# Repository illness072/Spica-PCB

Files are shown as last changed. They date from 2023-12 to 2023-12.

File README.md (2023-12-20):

# Spica PCB

PCB Data for Spica Keyboard

Spica is a 38-keys keyboard inspired by the Gemini Keyboard layout by zk-phi(@zk-phi). It was named by Sumiso(@kutsuhimo3).

* Gemini Keyboard by @zk-phi
  * https://github.com/zk-phi/gemini-keyboard

* Case Data
  * https://github.com/illness072/Spica-case/

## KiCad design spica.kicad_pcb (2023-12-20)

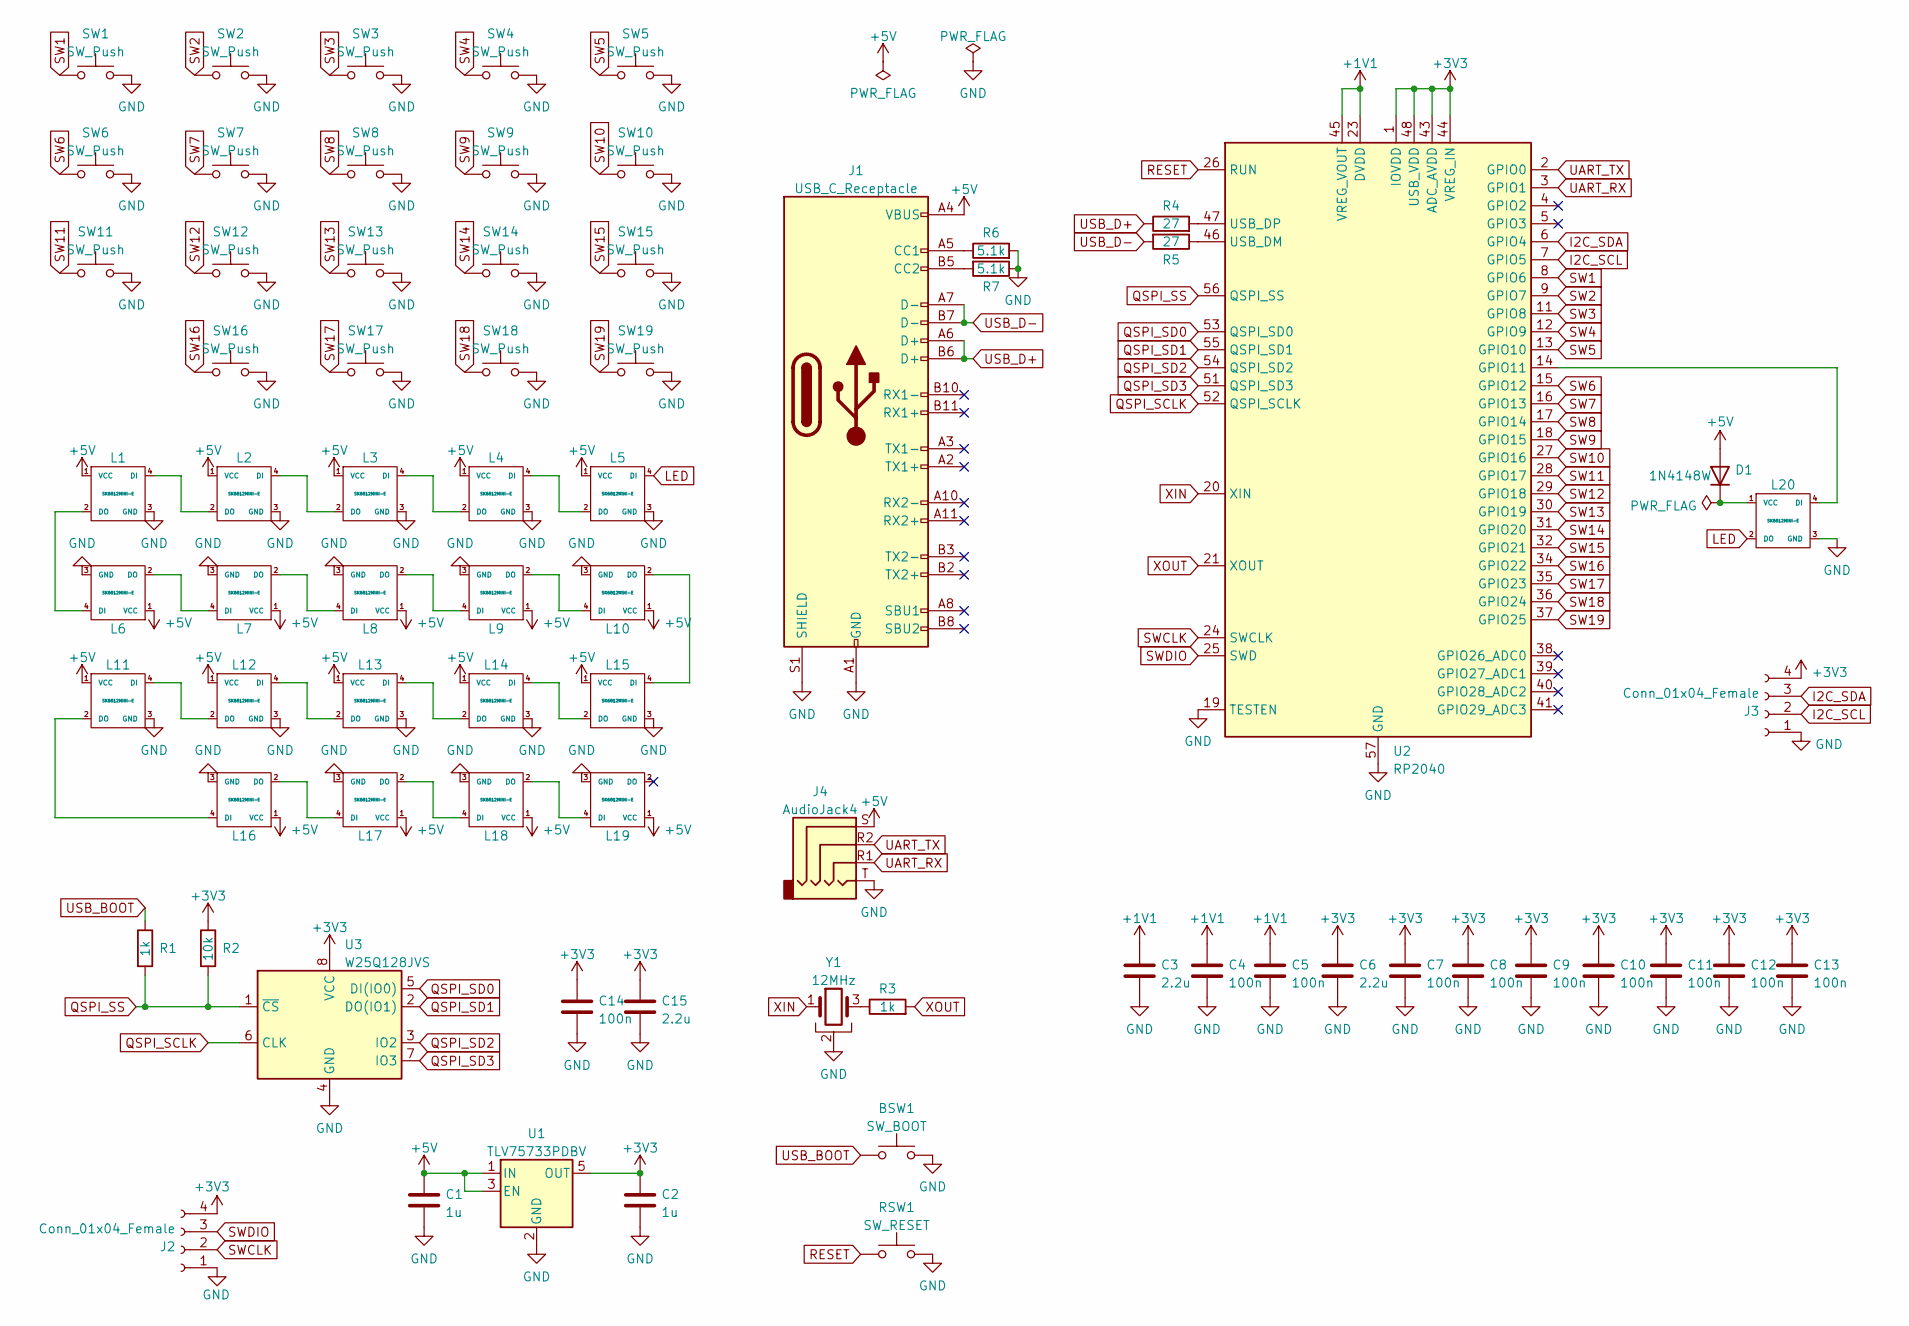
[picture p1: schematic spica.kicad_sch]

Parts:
BSW1: SW_BOOT; SW_Push_1P1T_NO_Vertical_Wuerth_434133025816
C1, C2: 1u; C_0402_1005Metric; LCSC C52923
C3, C6, C15: 2.2u; C_0402_1005Metric; LCSC C307418
C4, C5, C7, C8, C9, C10, C11, C12, C13: 100n; C_0402_1005Metric; LCSC C1525
C14: 100n; C_0402_1005Metric
D1: 1N4148W; D_SOD-123; LCSC C109203
J1: USB_C_Receptacle; USB_C_Receptacle_HRO_TYPE-C-31-M-12; LCSC C165948
J2, J3: Conn_01x04_Female; PinSocket_1x04_P2.54mm_Vertical
J4: AudioJack4; MJ-4PP-9_cross
L1, L2, L3, L4, L5, L6, L7, L8, L9, L10, L11, L12, L13, L14, L15, L16, L17, L18, L19, L20: SK6812MINI-E; SK6812MINI-E_Rev
R1, R3: 1k; R_0402_1005Metric; LCSC C11702
R2: 10k; R_0402_1005Metric; LCSC C25744
R4, R5: 27; R_0402_1005Metric; LCSC C25100
R6, R7: 5.1k; R_0402_1005Metric; LCSC C25905
RSW1: SW_RESET; SW_Push_1P1T_NO_Vertical_Wuerth_434133025816
SW1, SW2, SW3, SW4, SW5, SW7, SW8, SW9, SW10, SW12, SW13, SW14, SW15, SW16, SW17, SW18, SW19: SW_Push; MX_1.00u-reversible
SW6: SW_Push; MX_1.25u-reversible
SW11: SW_Push; MX_1.50u-reversible
U1: TLV75733PDBV; SOT-23-5; LCSC C485517
U2: RP2040; QFN-56-1EP_7x7mm_P0.4mm_EP3.2x3.2mm; LCSC C2040
U3: W25Q128JVS; WSON-8-1EP_6x5mm_P1.27mm_EP3.4x4.3mm; LCSC C190862
Y1: 12MHz; Resonator_SMD_Murata_CSTxExxV-3Pin_3.0x1.1mm; LCSC C341520

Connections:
+1V1: C3.1, C4.1, C5.1, U2.23 (DVDD), U2.45 (VREG_VOUT), U2.50 (DVDD)
+3V3: C2.1, C6.1, C7.1, C8.1, C9.1, C10.1, C11.1, C12.1, C13.1, C14.1, C15.1, J2.4, J3.4, R2.1, U1.5 (OUT), U2.1 (IOVDD), U2.10 (IOVDD), U2.22 (IOVDD), U2.33 (IOVDD), U2.42 (IOVDD), U2.43 (ADC_AVDD), U2.44 (VREG_IN), U2.48 (USB_VDD), U2.49 (IOVDD), U3.8 (VCC)
+5V: C1.1, D1.2 (A), J1.A4 (VBUS), J1.A9 (VBUS), J1.B4 (VBUS), J1.B9 (VBUS), J4.S, L1.1 (VCC), L2.1 (VCC), L3.1 (VCC), L4.1 (VCC), L5.1 (VCC), L6.1 (VCC), L7.1 (VCC), L8.1 (VCC), L9.1 (VCC), L10.1 (VCC), L11.1 (VCC), L12.1 (VCC), L13.1 (VCC), L14.1 (VCC), L15.1 (VCC), L16.1 (VCC), L17.1 (VCC), L18.1 (VCC), L19.1 (VCC), U1.1 (IN), U1.3 (EN)
GND: BSW1.2, C1.2, C2.2, C3.2, C4.2, C5.2, C6.2, C7.2, C8.2, C9.2, C10.2, C11.2, C12.2, C13.2, C14.2, C15.2, J1.A1 (GND), J1.A12 (GND), J1.B1 (GND), J1.B12 (GND), J1.S1 (SHIELD), J2.1, J3.1, J4.T, L1.3 (GND), L2.3 (GND), L3.3 (GND), L4.3 (GND), L5.3 (GND), L6.3 (GND), L7.3 (GND), L8.3 (GND), L9.3 (GND), L10.3 (GND), L11.3 (GND), L12.3 (GND), L13.3 (GND), L14.3 (GND), L15.3 (GND), L16.3 (GND), L17.3 (GND), L18.3 (GND), L19.3 (GND), L20.3 (GND), R6.2, R7.1, RSW1.2, SW1.2, SW2.2, SW3.2, SW4.2, SW5.2, SW6.2, SW7.2, SW8.2, SW9.2, SW10.2, SW11.2, SW12.2, SW13.2, SW14.2, SW15.2, SW16.2, SW17.2, SW18.2, SW19.2, U1.2 (GND), U2.19 (TESTEN), U2.57 (GND), U3.4 (GND), Y1.2
I2C_SCL: J3.2, U2.7 (GPIO5)
I2C_SDA: J3.3, U2.6 (GPIO4)
LED: L5.4 (DI), L20.2 (DO)
unnamed: D1.1 (K), L20.1 (VCC)
unnamed: J1.A5 (CC1), R6.1
unnamed: J1.B5 (CC2), R7.2
unnamed: L1.2 (DO), L6.4 (DI)
unnamed: L1.4 (DI), L2.2 (DO)
unnamed: L2.4 (DI), L3.2 (DO)
unnamed: L3.4 (DI), L4.2 (DO)
unnamed: L4.4 (DI), L5.2 (DO)
unnamed: L6.2 (DO), L7.4 (DI)
unnamed: L7.2 (DO), L8.4 (DI)
unnamed: L8.2 (DO), L9.4 (DI)
unnamed: L10.2 (DO), L15.4 (DI)
unnamed: L9.2 (DO), L10.4 (DI)
unnamed: L11.2 (DO), L16.4 (DI)
unnamed: L11.4 (DI), L12.2 (DO)
unnamed: L12.4 (DI), L13.2 (DO)
unnamed: L13.4 (DI), L14.2 (DO)
unnamed: L14.4 (DI), L15.2 (DO)
unnamed: L16.2 (DO), L17.4 (DI)
unnamed: L17.2 (DO), L18.4 (DI)
unnamed: L18.2 (DO), L19.4 (DI)
unnamed: L20.4 (DI), U2.14 (GPIO11)
unnamed: R3.1, Y1.3
unnamed: R4.2, U2.47 (USB_DP)
unnamed: R5.1, U2.46 (USB_DM)
QSPI_SCLK: U2.52 (QSPI_SCLK), U3.6 (CLK)
QSPI_SD0: U2.53 (QSPI_SD0), U3.5 (DI(IO0))
QSPI_SD1: U2.55 (QSPI_SD1), U3.2 (DO(IO1))
QSPI_SD2: U2.54 (QSPI_SD2), U3.3 (IO2)
QSPI_SD3: U2.51 (QSPI_SD3), U3.7 (IO3)
QSPI_SS: R1.2, R2.2, U2.56 (QSPI_SS), U3.1 (~CS)
RESET: RSW1.1, U2.26 (RUN)
SW1: SW1.1, U2.8 (GPIO6)
SW2: SW2.1, U2.9 (GPIO7)
SW3: SW3.1, U2.11 (GPIO8)
SW4: SW4.1, U2.12 (GPIO9)
SW5: SW5.1, U2.13 (GPIO10)
SW6: SW6.1, U2.15 (GPIO12)
SW7: SW7.1, U2.16 (GPIO13)
SW8: SW8.1, U2.17 (GPIO14)
SW9: SW9.1, U2.18 (GPIO15)
SW10: SW10.1, U2.27 (GPIO16)
SW11: SW11.1, U2.28 (GPIO17)
SW12: SW12.1, U2.29 (GPIO18)
SW13: SW13.1, U2.30 (GPIO19)
SW14: SW14.1, U2.31 (GPIO20)
SW15: SW15.1, U2.32 (GPIO21)
SW16: SW16.1, U2.34 (GPIO22)
SW17: SW17.1, U2.35 (GPIO23)
SW18: SW18.1, U2.36 (GPIO24)
SW19: SW19.1, U2.37 (GPIO25)
SWCLK: J2.2, U2.24 (SWCLK)
SWDIO: J2.3, U2.25 (SWD)
UART_RX: J4.R1, U2.3 (GPIO1)
UART_TX: J4.R2, U2.2 (GPIO0)
USB_BOOT: BSW1.1, R1.1
USB_D+: J1.A6 (D+), J1.B6 (D+), R4.1
USB_D-: J1.A7 (D-), J1.B7 (D-), R5.2
XIN: U2.20 (XIN), Y1.1
XOUT: R3.2, U2.21 (XOUT)

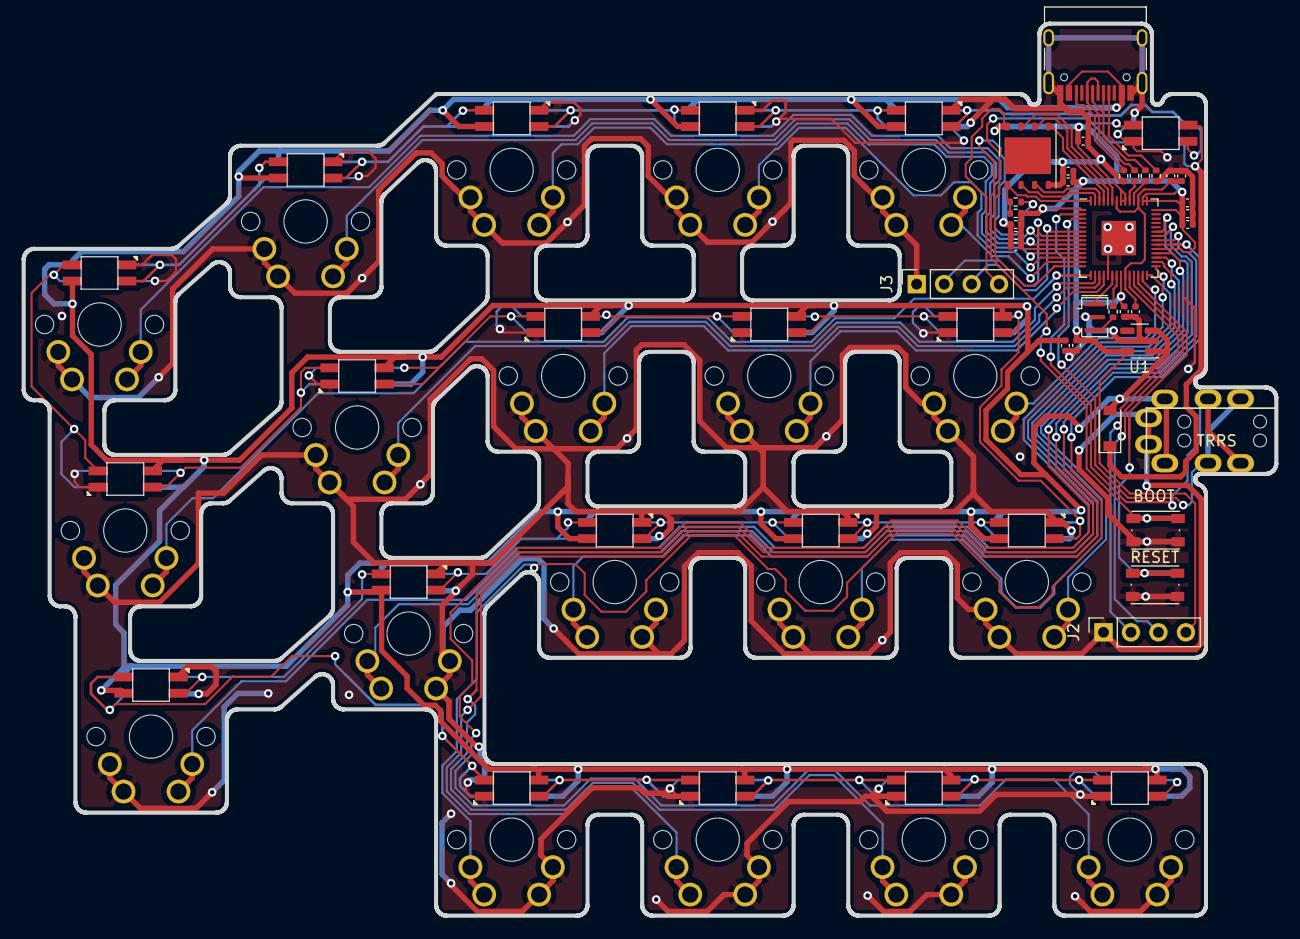
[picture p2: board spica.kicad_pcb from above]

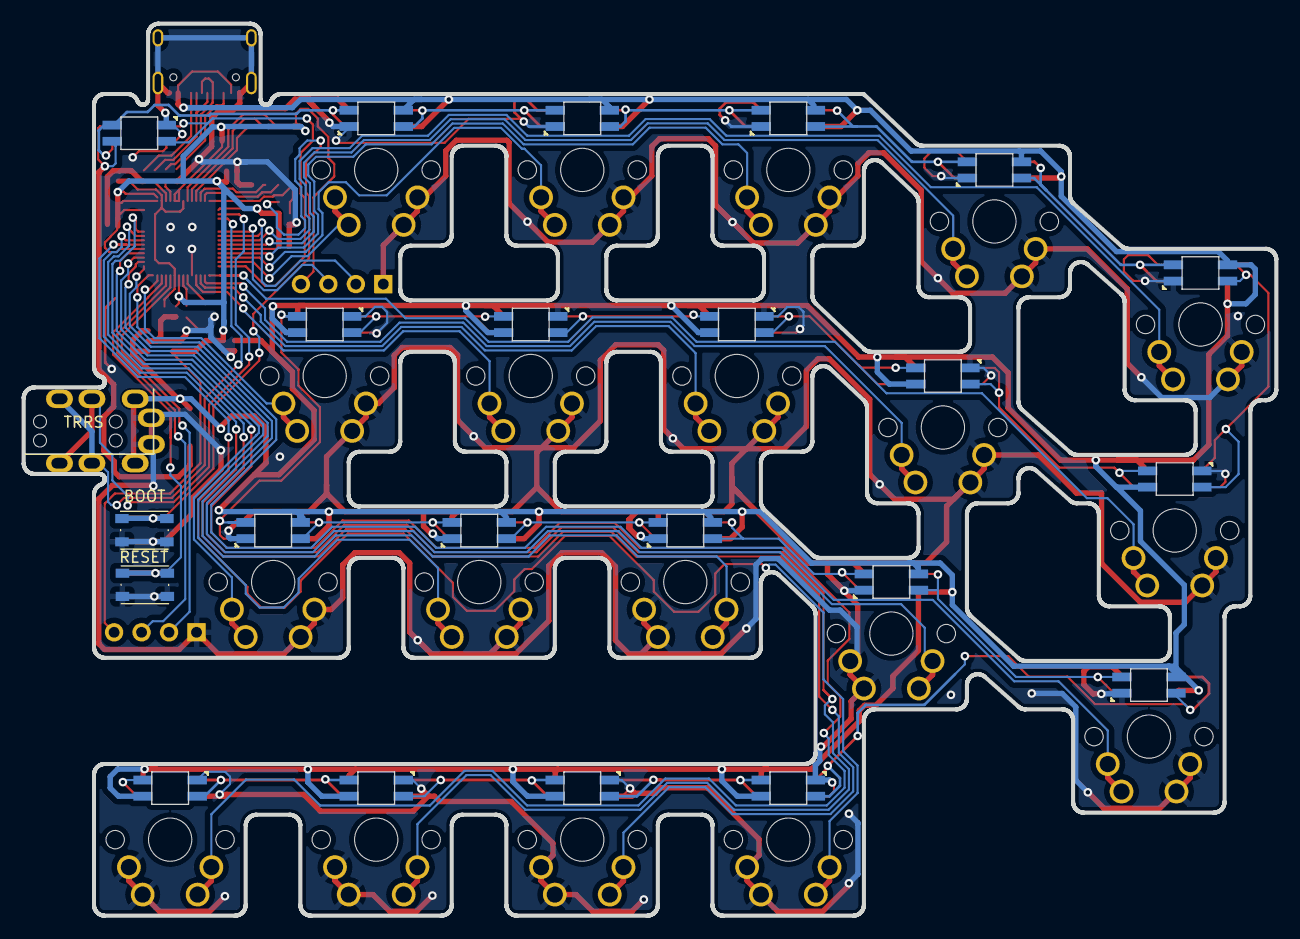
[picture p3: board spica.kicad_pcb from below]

Board: 2 copper layers, 115.8 x 82.5 mm, 72 parts (6 on the bottom side), 67 nets.
